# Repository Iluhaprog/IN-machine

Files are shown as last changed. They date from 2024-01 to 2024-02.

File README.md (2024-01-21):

> [!NOTE]
> Данный проект является учебным и предназначен в первую очередь для того
> чтобы разобраться и понять как работает вычислительное устройство на самом 
> низком уровне.

В данный момент проект на стадии разработки печатных плат и сборки физического 
устройства. 

Сейчас уже созданы и заказанны платы для АЛУ и Регистра флагов.

В процессе создания блок пользовательских регистров и счетчики команд и микро команд.

Сейчас в планы входят:
- [ ] - доработать схему управляющего устройства для работы с LCD 12864 экраном по SPI
- [ ] - разработка платы расширения для того, чтобы данное вычислительно устройство могло работать с датчиками.
- [ ] - изучение возможностей данного устройства и его параметров

Более подробно о базовых возможностях данного вычислительного устройства можно узнать в директории docs/

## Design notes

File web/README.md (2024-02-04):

Это веб версия ЭВМ. 
Здесь можно запустить свою программу написанную на jmasm.

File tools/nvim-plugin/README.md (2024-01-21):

Этот файл добавляет подсветку синтаксиса для jmasm файлов.

Для его использования этот файл необходимо добавить в **{path}/{to}/{nvim}/plugins**

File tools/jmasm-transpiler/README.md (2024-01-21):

Данный инструмент позволяет транспилировать asm код в код исполняемый моделью
в логисиме или для запуска непосредственно на физическом устройстве.

Установка
```
npm install -g .
```

Примеры можно посмотреть в директории **examples/**

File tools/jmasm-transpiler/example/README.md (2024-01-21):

В примере содеджаться 4 файла и дирректории rom-build и logisim-build

Создание фалов для запуска в моделе, которая находится в logism'e используется
следущая команда:
```sh
jmasm --source '.\jumps-example.jmasm' --output './logisim-build/jumps-example'
```

Для создания bin файла, который можно использовать для прошивки ROM
```sh
jmasm --source '.\jumps-example.jmasm' --output './rom-build/jumps-example.bin' --format BIN_FILE
```

> Содержимое созданных файлов соответствует общей спецификации.

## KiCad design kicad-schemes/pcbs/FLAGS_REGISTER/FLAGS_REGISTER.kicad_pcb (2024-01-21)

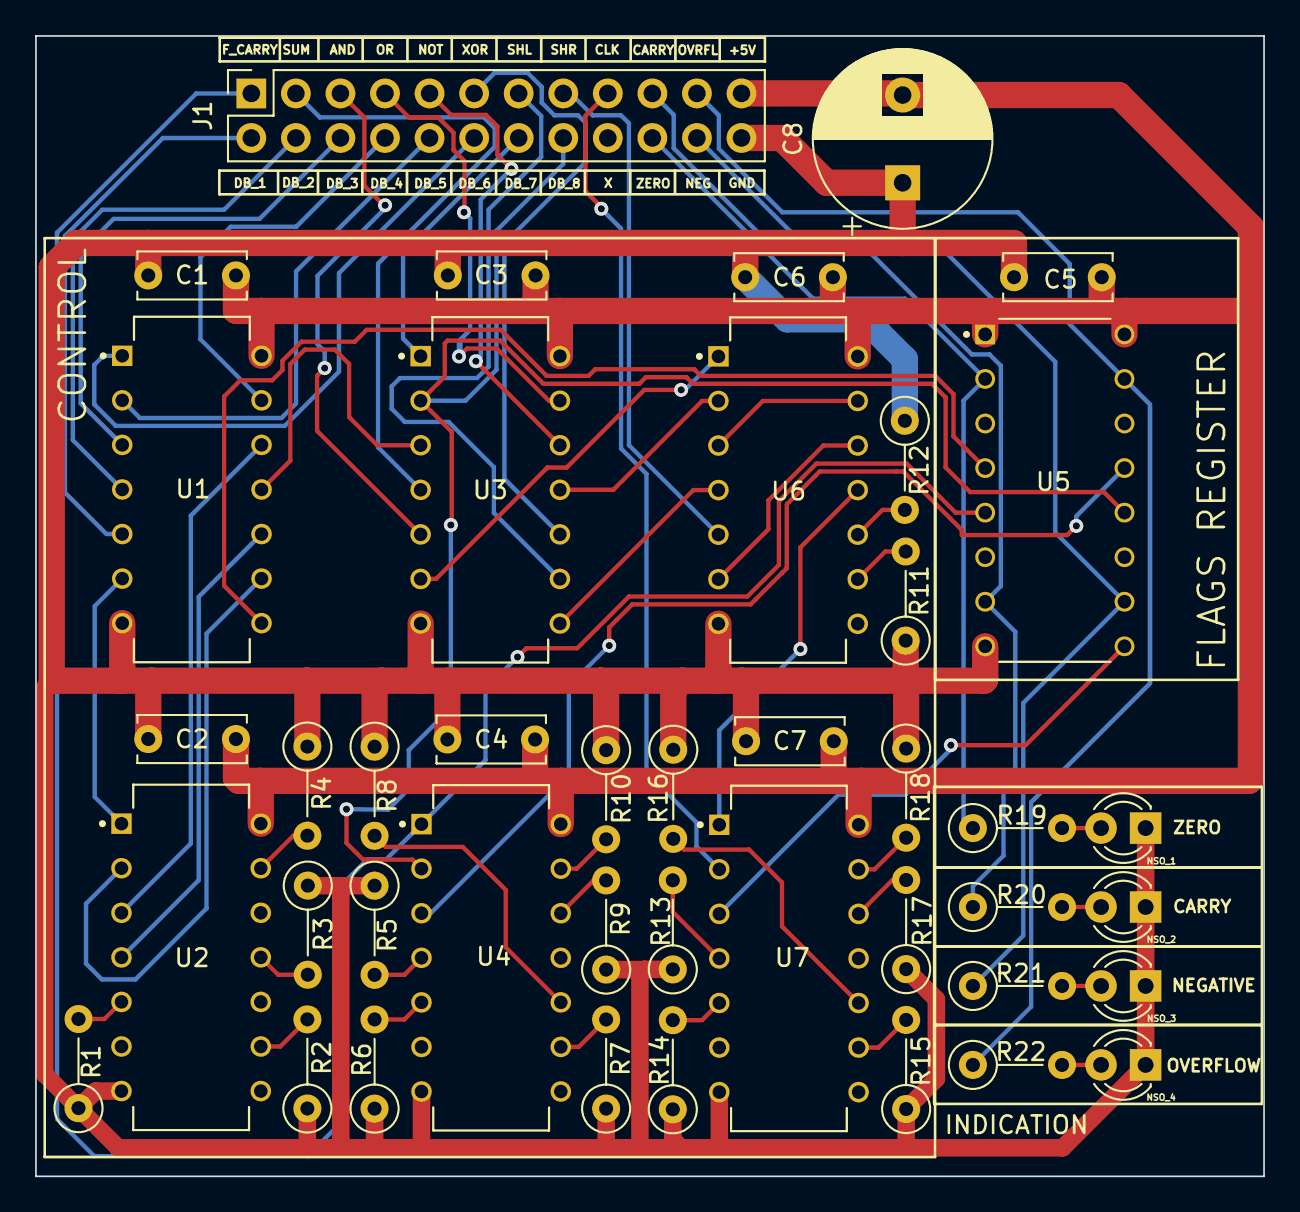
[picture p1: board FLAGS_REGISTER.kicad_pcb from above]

Board: 2 copper layers, 70.0 x 65.0 mm, 42 parts (0 on the bottom side), 59 nets.

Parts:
C1, C2, C3, C4, C5, C6, C7: C; C_Disc_D6.0mm_W2.5mm_P5.00mm
C8: C; CP_Radial_D10.0mm_P5.00mm
J1: Conn_02x12_Odd_Even; PinSocket_2x12_P2.54mm_Vertical
NSO_1, NSO_2, NSO_3, NSO_4: LED; LED_D3.0mm
R1, R2, R3, R4, R5, R6, R7, R8, R9, R10, R11, R12, R13, R14, R15, R16, R17, R18, R19, R20, R21, R22: R; R_Axial_DIN0207_L6.3mm_D2.5mm_P5.08mm_Vertical
U1: SN74HC27N; DIP794W45P254L1969H508Q14
U2: SN74HC14N; DIP794W45P254L1969H508Q14
U3, U6: SN74HC32N; DIP794W45P254L1969H508Q14
U4: SN74HC86N; DIP794W45P254L1969H508Q14
U5: SN74HC175N; DIP794W45P254L1969H508Q16
U7: SN74HC08N; DIP794W45P254L1969H508Q14

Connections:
+5V: C1.2, C2.2, C3.2, C4.2, C5.2, C6.2, C7.2, C8.2, J1.23, U1.14 (VCC), U2.14 (VCC), U3.14 (VCC), U4.14 (VCC), U5.1 (~CLR), U5.16 (VCC), U6.14 (VCC), U7.14 (VCC)
/CARRY: J1.19, R20.1, U5.7 (2Q)
/CLK: J1.17, U7.2 (1B)
/DB_1: J1.2, U1.5 (2C)
/DB_2: J1.4, U1.4 (2B)
/DB_3: J1.6, U1.3 (2A)
/DB_4: J1.8, U1.13 (1C)
/DB_5: J1.10, U1.2 (1B)
/DB_6: J1.12, U1.1 (1A)
/DB_7: J1.14, U3.1 (1A)
/DB_8: J1.16, U3.2 (1B), U4.2 (1B), U5.12 (3D)
/F_CARRY: J1.1, U4.1 (1A), U5.5 (2D)
/NEGATIVE: J1.22, R21.1, U5.10 (3Q)
/OVERFLOW: J1.21, R22.1, U5.15 (4Q)
/ZERO: J1.20, R19.1, U5.2 (1Q)
/n_AND_EN: J1.5, U3.5 (2B)
/n_NOT_EN: J1.9, U3.12 (4A)
/n_OR_EN: J1.7, U3.13 (4B)
/n_SHL_EN: J1.13, U3.9 (3A)
/n_SHR_EN: J1.15, U6.5 (2B)
/n_SUM_EN: J1.3, U3.4 (2A)
/n_XOR_EN: J1.11, U3.10 (3B)
CLK_FLAGS: U5.9 (CLK), U7.3 (1Y)
EN_WRITE_FLAGS: U6.11 (4Y), U7.1 (1A)
F_OVERFLOW: U4.3 (1Y), U5.13 (4D)
F_ZERO: U1.8 (3Y), U5.4 (1D)
GND: C1.1, C2.1, C3.1, C4.1, C5.1, C6.1, C7.1, C8.1, J1.24, NSO_1.1 (K), NSO_2.1 (K), NSO_3.1 (K), NSO_4.1 (K), R1.1, R2.1, R3.1, R4.1, R5.1, R6.1, R7.1, R8.1, R9.1, R10.1, R11.1, R12.1, R13.1, R14.1, R15.1, R16.1, R17.1, R18.1, U1.7 (GND), U2.7 (GND), U3.7 (GND), U4.7 (GND), U5.8 (GND), U6.7 (GND), U7.7 (GND)
NOT_OR_OR: U3.11 (4Y), U6.2 (1B)
unnamed: NSO_1.2 (A), R19.2
unnamed: NSO_2.2 (A), R20.2
unnamed: NSO_3.2 (A), R21.2
unnamed: NSO_4.2 (A), R22.2
unnamed: R1.2, U2.5 (3A)
unnamed: R2.2, U2.9 (4A)
unnamed: R3.2, U2.11 (5A)
unnamed: R4.2, U2.13 (6A)
unnamed: R5.2, U4.4 (2A)
unnamed: R6.2, U4.5 (2B)
unnamed: R7.2, U4.9 (3A)
unnamed: R8.2, U4.10 (3B)
unnamed: R9.2, U4.12 (4A)
unnamed: R10.2, U4.13 (4B)
unnamed: R11.2, U6.9 (3A)
unnamed: R12.2, U6.10 (3B)
unnamed: R13.2, U7.4 (2A)
unnamed: R14.2, U7.5 (2B)
unnamed: R15.2, U7.9 (3A)
unnamed: R16.2, U7.10 (3B)
unnamed: R17.2, U7.12 (4A)
unnamed: R18.2, U7.13 (4B)
O1_O2_O3: U1.6 (2Y), U2.1 (1A)
O4_O5_O6: U1.12 (1Y), U2.3 (2A)
SUM_OR_AND: U3.6 (2Y), U6.1 (1A)
SUM_OR_AND_OR_NOT_OR_OR: U6.3 (1Y), U6.13 (4B)
XOR_OR_SHL: U3.8 (3Y), U6.4 (2A)
XOR_OR_SHL_OR_SHR: U6.6 (2Y), U6.12 (4A)
n_O1_O2_O3: U1.9 (3A), U2.2 (1Y)
n_O4_O5_O6: U1.10 (3B), U2.4 (2Y)
n_O7_O8: U1.11 (3C), U3.3 (1Y)

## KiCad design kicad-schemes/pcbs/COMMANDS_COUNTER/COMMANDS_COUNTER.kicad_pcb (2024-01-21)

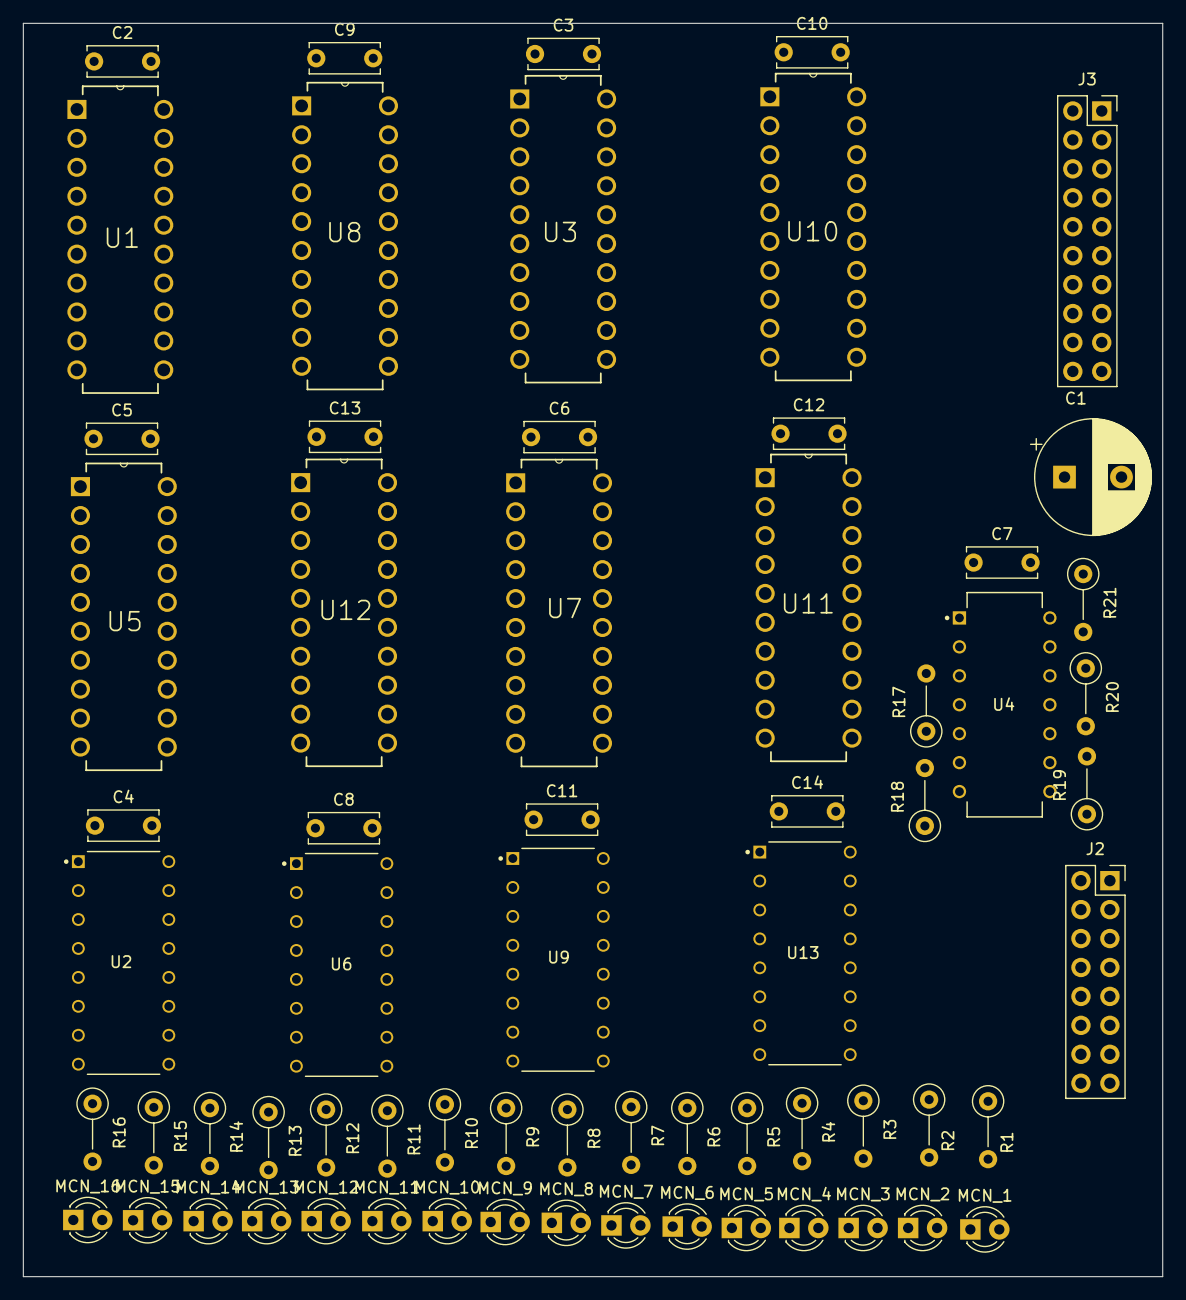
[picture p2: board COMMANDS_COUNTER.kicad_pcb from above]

Board: 2 copper layers, 100.0 x 110.0 mm, 66 parts (0 on the bottom side), 109 nets, no tracks yet.

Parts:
C1: C; CP_Radial_D10.0mm_P5.00mm
C2, C3, C4, C5, C6, C7, C8, C9, C10, C11, C12, C13, C14: C; C_Disc_D6.0mm_W2.5mm_P5.00mm
J2: Conn_02x08_Odd_Even; PinSocket_2x08_P2.54mm_Vertical
J3: Conn_02x10_Odd_Even; PinSocket_2x10_P2.54mm_Vertical
MCN_1, MCN_2, MCN_3, MCN_4, MCN_5, MCN_6, MCN_7, MCN_8, MCN_9, MCN_10, MCN_11, MCN_12, MCN_13, MCN_14, MCN_15, MCN_16: LED; LED_D3.0mm
R1, R2, R3, R4, R5, R6, R7, R8, R9, R10, R11, R12, R13, R14, R15, R16, R17, R18, R19, R20, R21: R; R_Axial_DIN0207_L6.3mm_D2.5mm_P5.08mm_Vertical
U1, U3, U8, U10: SN74HC377N; DIP254P762X508-20
U2, U6, U9, U13: SN74HC163N; DIP794W45P254L1969H508Q16
U4: SN74HC14N; DIP794W45P254L1969H508Q14
U5, U7, U11, U12: SN74HC244N; DIP254P762X508-20

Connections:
/AB1: J2.1, R1.1, U2.14 (QA), U3.3 (1D)
/AB2: J2.3, R2.1, U2.13 (QB), U3.4 (2D)
/AB3: J2.5, R3.1, U2.12 (QC), U3.7 (3D)
/AB4: J2.7, R4.1, U2.11 (QD), U3.8 (4D)
/AB5: J2.9, R5.1, U3.13 (5D), U6.14 (QA)
/AB6: J2.11, R6.1, U3.14 (6D), U6.13 (QB)
/AB7: J2.13, R7.1, U3.17 (7D), U6.12 (QC)
/AB8: J2.15, R8.1, U3.18 (8D), U6.11 (QD)
/AB9: J2.2, R9.1, U9.14 (QA), U10.3 (1D)
/AB10: J2.4, R10.1, U9.13 (QB), U10.4 (2D)
/AB11: J2.6, R11.1, U9.12 (QC), U10.7 (3D)
/AB12: J2.8, R12.1, U9.11 (QD), U10.8 (4D)
/AB13: J2.10, R13.1, U10.13 (5D), U13.14 (QA)
/AB14: J2.12, R14.1, U10.14 (6D), U13.13 (QB)
/AB15: J2.14, R15.1, U10.17 (7D), U13.12 (QC)
/AB16: J2.16, R16.1, U10.18 (8D), U13.11 (QD)
/CAR_n_EN1: J3.18, U3.1 (~CLKEN)
/CAR_n_EN2: J3.20, U10.1 (~CLKEN)
/CAR_n_EN_Out: J3.16, U7.1 (1~OE), U7.19 (2~OE), U11.1 (1~OE), U11.19 (2~OE)
/C_n_Clear: J3.4, U2.1 (~CLR), U6.1 (~CLR), U9.1 (~CLR), U13.1 (~CLR)
/C_n_Enable_Counter: J3.2, U2.7 (ENP), U6.7 (ENP), U9.7 (ENP), U13.7 (ENP)
/C_n_Enable_Load: J3.6, U2.9 (~LOAD), U6.9 (~LOAD), U9.9 (~LOAD), U13.9 (~LOAD)
/DB1: J3.5, U1.13 (5D), U8.13 (5D)
/DB2: J3.7, U1.8 (4D), U8.8 (4D)
/DB3: J3.9, U1.14 (6D), U8.14 (6D)
/DB4: J3.11, U1.7 (3D), U8.7 (3D)
/DB5: J3.13, U1.17 (7D), U8.17 (7D)
/DB6: J3.15, U1.4 (2D), U8.4 (2D)
/DB7: J3.17, U1.18 (8D), U8.18 (8D)
/DB8: J3.19, U1.3 (1D), U8.3 (1D)
/GND: C1.1, C2.1, C3.1, C4.1, C5.1, C6.1, C7.1, C8.1, C9.1, C10.1, C11.1, C12.1, C13.1, C14.1, J3.1, MCN_1.1 (K), MCN_2.1 (K), MCN_3.1 (K), MCN_4.1 (K), MCN_5.1 (K), MCN_6.1 (K), MCN_7.1 (K), MCN_8.1 (K), MCN_9.1 (K), MCN_10.1 (K), MCN_11.1 (K), MCN_12.1 (K), MCN_13.1 (K), MCN_14.1 (K), MCN_15.1 (K), MCN_16.1 (K), R17.1, R18.1, R19.1, R20.1, R21.1, U1.10 (GND), U2.8 (GND), U3.10 (GND), U4.7 (GND), U5.10 (GND), U6.8 (GND), U7.10 (GND), U8.10 (GND), U9.8 (GND), U10.10 (GND), U11.10 (GND), U12.10 (GND), U13.8 (GND)
/POWER: C1.2, C2.2, C3.2, C4.2, C5.2, C6.2, C7.2, C8.2, C9.2, C10.2, C11.2, C12.2, C13.2, C14.2, J3.3, U1.20 (VCC), U2.10 (ENT), U2.16 (VCC), U3.20 (VCC), U4.14 (VCC), U5.20 (VCC), U6.16 (VCC), U7.20 (VCC), U8.20 (VCC), U9.16 (VCC), U10.20 (VCC), U11.20 (VCC), U12.20 (VCC), U13.16 (VCC)
/UAR_n_EN1: J3.8, U1.1 (~CLKEN)
/UAR_n_EN2: J3.10, U8.1 (~CLKEN)
/UAR_n_EN_Out: J3.12, U5.1 (1~OE), U5.19 (2~OE), U12.1 (1~OE), U12.19 (2~OE)
CLK: J3.14, U1.11 (CLK), U2.2 (CLK), U4.1 (1A), U6.2 (CLK), U8.11 (CLK), U9.2 (CLK), U13.2 (CLK)
CR_O_1: U2.3 (A), U5.3 (2Y4), U7.18 (1Y1)
CR_O_2: U2.4 (B), U5.18 (1Y1), U7.16 (1Y2)
CR_O_3: U2.5 (C), U5.5 (2Y3), U7.14 (1Y3)
CR_O_4: U2.6 (D), U5.16 (1Y2), U7.12 (1Y4)
CR_O_5: U5.7 (2Y2), U6.3 (A), U7.9 (2Y1)
CR_O_6: U5.14 (1Y3), U6.4 (B), U7.7 (2Y2)
CR_O_7: U5.9 (2Y1), U6.5 (C), U7.5 (2Y3)
CR_O_8: U5.12 (1Y4), U6.6 (D), U7.3 (2Y4)
CR_O_9: U9.3 (A), U11.18 (1Y1), U12.3 (2Y4)
CR_O_10: U9.4 (B), U11.16 (1Y2), U12.18 (1Y1)
CR_O_11: U9.5 (C), U11.14 (1Y3), U12.5 (2Y3)
CR_O_12: U9.6 (D), U11.12 (1Y4), U12.16 (1Y2)
CR_O_13: U11.9 (2Y1), U12.7 (2Y2), U13.3 (A)
CR_O_14: U11.7 (2Y2), U12.14 (1Y3), U13.4 (B)
CR_O_15: U11.5 (2Y3), U12.9 (2Y1), U13.5 (C)
CR_O_16: U11.3 (2Y4), U12.12 (1Y4), U13.6 (D)
C_RCO_1: U2.15 (RCO), U6.10 (ENT)
C_RCO_2: U6.15 (RCO), U9.10 (ENT)
C_RCO_3: U9.15 (RCO), U13.10 (ENT)
unnamed: MCN_1.2 (A), R1.2
unnamed: MCN_2.2 (A), R2.2
unnamed: MCN_3.2 (A), R3.2
unnamed: MCN_4.2 (A), R4.2
unnamed: MCN_5.2 (A), R5.2
unnamed: MCN_6.2 (A), R6.2
unnamed: MCN_7.2 (A), R7.2
unnamed: MCN_8.2 (A), R8.2
unnamed: MCN_9.2 (A), R9.2
unnamed: MCN_10.2 (A), R10.2
unnamed: MCN_11.2 (A), R11.2
unnamed: MCN_12.2 (A), R12.2
unnamed: MCN_13.2 (A), R13.2
unnamed: MCN_14.2 (A), R14.2
unnamed: MCN_15.2 (A), R15.2
unnamed: MCN_16.2 (A), R16.2
unnamed: R17.2, U4.3 (2A)
unnamed: R18.2, U4.5 (3A)
unnamed: R19.2, U4.9 (4A)
unnamed: R20.2, U4.11 (5A)
unnamed: R21.2, U4.13 (6A)
in_UAR_O_1: U1.12 (5Q), U5.17 (2A4)
in_UAR_O_2: U1.9 (4Q), U5.2 (1A1)
in_UAR_O_3: U1.15 (6Q), U5.15 (2A3)
in_UAR_O_4: U1.6 (3Q), U5.4 (1A2)
in_UAR_O_5: U1.16 (7Q), U5.13 (2A2)
in_UAR_O_6: U1.5 (2Q), U5.6 (1A3)
in_UAR_O_7: U1.19 (8Q), U5.11 (2A1)
in_UAR_O_8: U1.2 (1Q), U5.8 (1A4)
in_UAR_O_9: U8.12 (5Q), U12.17 (2A4)
in_UAR_O_10: U8.9 (4Q), U12.2 (1A1)
in_UAR_O_11: U8.15 (6Q), U12.15 (2A3)
in_UAR_O_12: U8.6 (3Q), U12.4 (1A2)
in_UAR_O_13: U8.16 (7Q), U12.13 (2A2)
in_UAR_O_14: U8.5 (2Q), U12.6 (1A3)
in_UAR_O_15: U8.19 (8Q), U12.11 (2A1)
in_UAR_O_16: U8.2 (1Q), U12.8 (1A4)
in_СAR_O_1: U3.2 (1Q), U7.2 (1A1)
in_СAR_O_2: U3.5 (2Q), U7.4 (1A2)
in_СAR_O_3: U3.6 (3Q), U7.6 (1A3)
in_СAR_O_4: U3.9 (4Q), U7.8 (1A4)
in_СAR_O_5: U3.12 (5Q), U7.11 (2A1)
in_СAR_O_6: U3.15 (6Q), U7.13 (2A2)
in_СAR_O_7: U3.16 (7Q), U7.15 (2A3)
in_СAR_O_8: U3.19 (8Q), U7.17 (2A4)
in_СAR_O_9: U10.2 (1Q), U11.2 (1A1)
in_СAR_O_10: U10.5 (2Q), U11.4 (1A2)
in_СAR_O_11: U10.6 (3Q), U11.6 (1A3)
in_СAR_O_12: U10.9 (4Q), U11.8 (1A4)
in_СAR_O_13: U10.12 (5Q), U11.11 (2A1)
in_СAR_O_14: U10.15 (6Q), U11.13 (2A2)
in_СAR_O_15: U10.16 (7Q), U11.15 (2A3)
in_СAR_O_16: U10.19 (8Q), U11.17 (2A4)
n_CLK: U3.11 (CLK), U4.2 (1Y), U10.11 (CLK)

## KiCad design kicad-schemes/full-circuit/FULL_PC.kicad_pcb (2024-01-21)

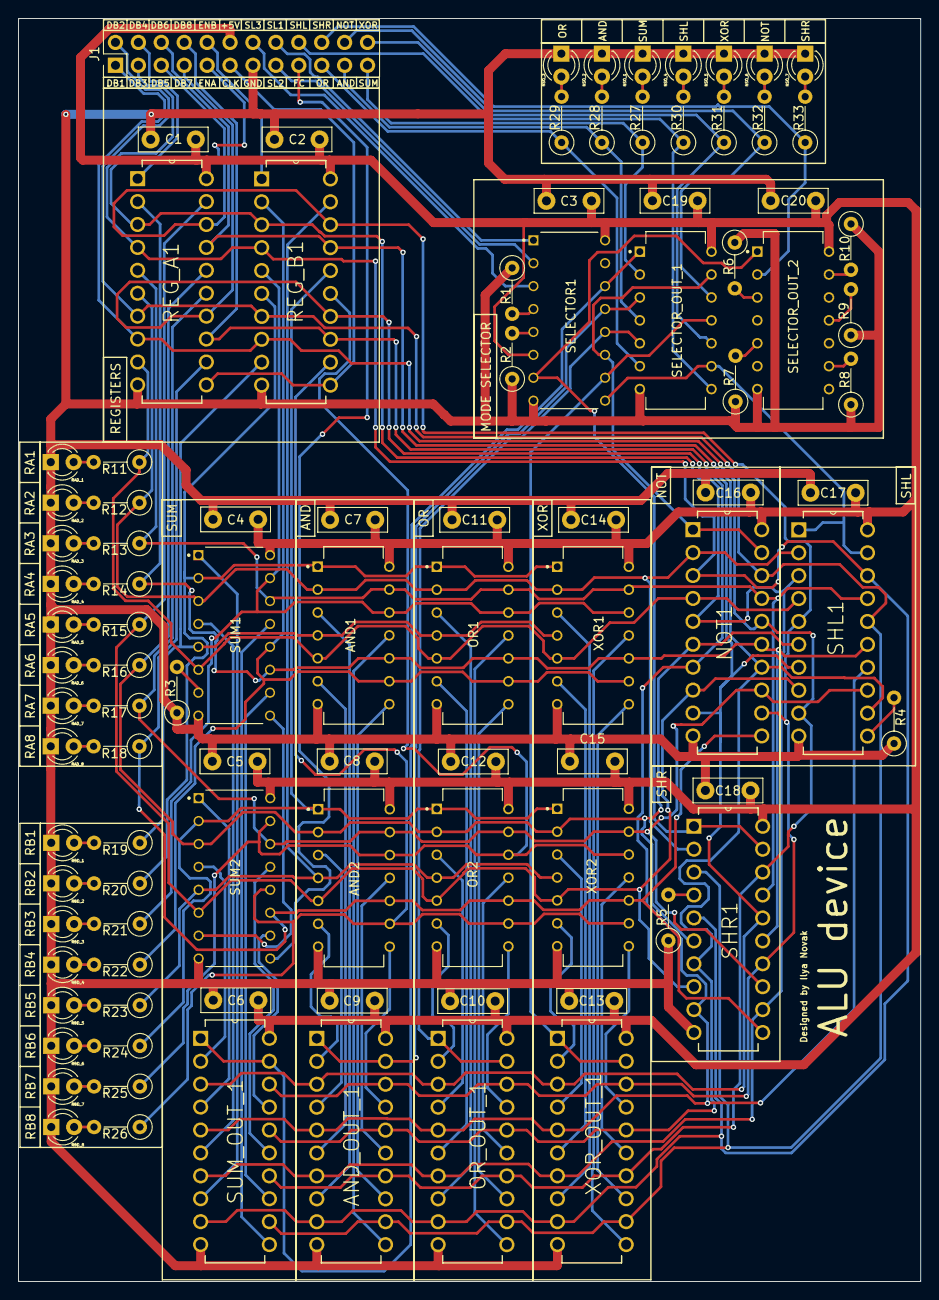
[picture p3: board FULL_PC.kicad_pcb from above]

Board: 2 copper layers, 100.0 x 140.0 mm, 97 parts (0 on the bottom side), 113 nets.

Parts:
AND1, AND2: SN74HC08N; DIP794W45P254L1969H508Q14
AND_OUT_1: SN74HC244N; DIP254P762X508-20
C1, C2, C3, C4, C5, C6, C7, C8, C9, C10, C11, C12, C13, C14, C15, C16, C17, C18, C19, C20: C; C_Disc_D7.5mm_W2.5mm_P5.00mm
J1: Conn_02x12_Counter_Clockwise; PinHeader_2x12_P2.54mm_Vertical
NOT1: SN74HC240N; DIP254P762X508-20
NSO_1, NSO_2, NSO_3, NSO_4, NSO_5, NSO_6, NSO_7: LED; LED_D3.0mm
OR1, OR2: SN74HC32N; DIP794W45P254L1969H508Q14
OR_OUT_1: SN74HC244N; DIP254P762X508-20
R1, R2, R3, R4, R5, R6, R7, R8, R9, R10, R11, R12, R13, R14, R15, R16, R17, R18, R19, R20, R21, R22, R23, R24, R25, R26, R27, R28, R29, R30, R31, R32, R33: R; R_Axial_DIN0207_L6.3mm_D2.5mm_P5.08mm_Vertical
RAD_1, RAD_2, RAD_3, RAD_4, RAD_5, RAD_6, RAD_7, RAD_8: LED; LED_D3.0mm
RBD_1, RBD_2, RBD_3, RBD_4, RBD_5, RBD_6, RBD_7, RBD_8: LED; LED_D3.0mm
REG_A1: SN74HC377N; DIP254P762X508-20
REG_B1: SN74HC377N; DIP254P762X508-20
SELECTOR1: SN74HC138N; DIP794W45P254L1969H508Q16
SELECTOR_OUT_1, SELECTOR_OUT_2: SN74HC14N; DIP794W45P254L1969H508Q14
SHL1: SN74HC244N; DIP254P762X508-20
SHR1: SN74HC244N; DIP254P762X508-20
SUM1, SUM2: SN74HC283N; DIP794W45P254L1969H508Q16
SUM_OUT_1: SN74HC244N; DIP254P762X508-20
XOR1, XOR2: SN74HC86N; DIP794W45P254L1969H508Q14
XOR_OUT_1: SN74HC244N; DIP254P762X508-20

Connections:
+5V: AND1.14 (VCC), AND2.14 (VCC), AND_OUT_1.20 (VCC), C1.2, C2.2, C3.2, C4.2, C5.2, C6.2, C7.2, C8.2, C9.2, C10.2, C11.2, C12.2, C13.2, C14.2, C15.2, C16.2, C17.2, C18.2, C19.2, C20.2, J1.12, NOT1.20 (VCC), OR1.14 (VCC), OR2.14 (VCC), OR_OUT_1.20 (VCC), REG_A1.20 (VCC), REG_B1.20 (VCC), SELECTOR1.6 (G1), SELECTOR1.16 (VCC), SELECTOR_OUT_1.14 (VCC), SELECTOR_OUT_2.14 (VCC), SHL1.20 (VCC), SHR1.20 (VCC), SUM1.16 (Vcc), SUM2.16 (Vcc), SUM_OUT_1.20 (VCC), XOR1.14 (VCC), XOR2.14 (VCC), XOR_OUT_1.20 (VCC)
/ALU/CLK: J1.11, REG_A1.11 (CLK), REG_B1.11 (CLK)
/ALU/DB_1: AND_OUT_1.14 (1Y3), J1.1, NOT1.16 (1Y2), OR_OUT_1.14 (1Y3), REG_A1.8 (4D), REG_B1.8 (4D), SHL1.9 (2Y1), SHR1.18 (1Y1), SUM_OUT_1.14 (1Y3), XOR_OUT_1.14 (1Y3)
/ALU/DB_2: AND_OUT_1.12 (1Y4), J1.2, NOT1.18 (1Y1), OR_OUT_1.12 (1Y4), REG_A1.7 (3D), REG_B1.7 (3D), SHL1.16 (1Y2), SHR1.3 (2Y4), SUM_OUT_1.12 (1Y4), XOR_OUT_1.12 (1Y4)
/ALU/DB_3: AND_OUT_1.9 (2Y1), J1.3, NOT1.3 (2Y4), OR_OUT_1.9 (2Y1), REG_A1.4 (2D), REG_B1.4 (2D), SHL1.18 (1Y1), SHR1.5 (2Y3), SUM_OUT_1.9 (2Y1), XOR_OUT_1.9 (2Y1)
/ALU/DB_4: AND_OUT_1.7 (2Y2), J1.4, NOT1.5 (2Y3), OR_OUT_1.7 (2Y2), REG_A1.3 (1D), REG_B1.3 (1D), SHL1.3 (2Y4), SHR1.12 (1Y4), SUM_OUT_1.7 (2Y2), XOR_OUT_1.7 (2Y2)
/ALU/DB_5: AND_OUT_1.18 (1Y1), J1.5, NOT1.12 (1Y4), OR_OUT_1.18 (1Y1), REG_A1.18 (8D), REG_B1.18 (8D), SHL1.5 (2Y3), SHR1.14 (1Y3), SUM_OUT_1.18 (1Y1), XOR_OUT_1.18 (1Y1)
/ALU/DB_6: AND_OUT_1.16 (1Y2), J1.6, NOT1.14 (1Y3), OR_OUT_1.16 (1Y2), REG_A1.17 (7D), REG_B1.17 (7D), SHL1.12 (1Y4), SHR1.7 (2Y2), SUM_OUT_1.16 (1Y2), XOR_OUT_1.16 (1Y2)
/ALU/DB_7: AND_OUT_1.5 (2Y3), J1.7, NOT1.7 (2Y2), OR_OUT_1.5 (2Y3), REG_A1.14 (6D), REG_B1.14 (6D), SHL1.14 (1Y3), SHR1.9 (2Y1), SUM_OUT_1.5 (2Y3), XOR_OUT_1.5 (2Y3)
/ALU/DB_8: AND_OUT_1.3 (2Y4), J1.8, NOT1.9 (2Y1), OR_OUT_1.3 (2Y4), REG_A1.13 (5D), REG_B1.13 (5D), SHL1.7 (2Y2), SHR1.16 (1Y2), SUM_OUT_1.3 (2Y4), XOR_OUT_1.3 (2Y4)
/ALU/EN_A: J1.9, REG_A1.1 (~CLKEN)
/ALU/EN_B: J1.10, REG_B1.1 (~CLKEN)
/ALU/F_CARRY: J1.17, SUM2.9 (C4)
/ALU/SL_1: J1.16, SELECTOR1.1 (A)
/ALU/SL_2: J1.15, SELECTOR1.2 (B)
/ALU/SL_3: J1.14, SELECTOR1.3 (C)
/ALU/n_AND_EN: J1.21, R28.1, SELECTOR_OUT_1.4 (2Y)
/ALU/n_NOT_EN: J1.22, R32.1, SELECTOR_OUT_1.12 (6Y)
/ALU/n_OR_EN: J1.19, R29.1, SELECTOR_OUT_1.6 (3Y)
/ALU/n_SHL_EN: J1.18, R30.1, SELECTOR_OUT_1.8 (4Y)
/ALU/n_SHR_EN: J1.20, R33.1, SELECTOR_OUT_2.2 (1Y)
/ALU/n_SUM_EN: J1.23, R27.1, SELECTOR_OUT_1.2 (1Y)
/ALU/n_XOR_EN: J1.24, R31.1, SELECTOR_OUT_1.10 (5Y)
AND_EN: AND_OUT_1.1 (1~OE), AND_OUT_1.19 (2~OE), SELECTOR1.13 (Y2), SELECTOR_OUT_1.3 (2A)
AND_O_1: AND1.6 (2Y), AND_OUT_1.6 (1A3)
AND_O_2: AND1.3 (1Y), AND_OUT_1.8 (1A4)
AND_O_3: AND1.11 (4Y), AND_OUT_1.11 (2A1)
AND_O_4: AND1.8 (3Y), AND_OUT_1.13 (2A2)
AND_O_5: AND2.6 (2Y), AND_OUT_1.2 (1A1)
AND_O_6: AND2.3 (1Y), AND_OUT_1.4 (1A2)
AND_O_7: AND2.11 (4Y), AND_OUT_1.15 (2A3)
AND_O_8: AND2.8 (3Y), AND_OUT_1.17 (2A4)
GND: AND1.7 (GND), AND2.7 (GND), AND_OUT_1.10 (GND), C1.1, C2.1, C3.1, C4.1, C5.1, C6.1, C7.1, C8.1, C9.1, C10.1, C11.1, C12.1, C13.1, C14.1, C15.1, C16.1, C17.1, C18.1, C19.1, C20.1, J1.13, NOT1.10 (GND), NSO_1.1 (K), NSO_2.1 (K), NSO_3.1 (K), NSO_4.1 (K), NSO_5.1 (K), NSO_6.1 (K), NSO_7.1 (K), OR1.7 (GND), OR2.7 (GND), OR_OUT_1.10 (GND), R1.1, R2.1, R3.1, R4.1, R5.1, R6.1, R7.1, R8.1, R9.1, R10.1, RAD_1.1 (K), RAD_2.1 (K), RAD_3.1 (K), RAD_4.1 (K), RAD_5.1 (K), RAD_6.1 (K), RAD_7.1 (K), RAD_8.1 (K), RBD_1.1 (K), RBD_2.1 (K), RBD_3.1 (K), RBD_4.1 (K), RBD_5.1 (K), RBD_6.1 (K), RBD_7.1 (K), RBD_8.1 (K), REG_A1.10 (GND), REG_B1.10 (GND), SELECTOR1.8 (GND), SELECTOR_OUT_1.7 (GND), SELECTOR_OUT_2.7 (GND), SHL1.10 (GND), SHR1.10 (GND), SUM1.8 (GND), SUM2.8 (GND), SUM_OUT_1.10 (GND), XOR1.7 (GND), XOR2.7 (GND), XOR_OUT_1.10 (GND)
NOT_EN: NOT1.1 (1~OE), NOT1.19 (2~OE), SELECTOR1.11 (Y4), SELECTOR_OUT_1.13 (6A)
unnamed: NSO_1.2 (A), R27.2
unnamed: NSO_2.2 (A), R28.2
unnamed: NSO_3.2 (A), R29.2
unnamed: NSO_4.2 (A), R30.2
unnamed: NSO_5.2 (A), R31.2
unnamed: NSO_6.2 (A), R32.2
unnamed: NSO_7.2 (A), R33.2
unnamed: R11.2, RAD_1.2 (A)
unnamed: R12.2, RAD_2.2 (A)
unnamed: R13.2, RAD_3.2 (A)
unnamed: R14.2, RAD_4.2 (A)
unnamed: R15.2, RAD_5.2 (A)
unnamed: R16.2, RAD_6.2 (A)
unnamed: R17.2, RAD_7.2 (A)
unnamed: R18.2, RAD_8.2 (A)
unnamed: R19.2, RBD_1.2 (A)
unnamed: R20.2, RBD_2.2 (A)
unnamed: R21.2, RBD_3.2 (A)
unnamed: R22.2, RBD_4.2 (A)
unnamed: R23.2, RBD_5.2 (A)
unnamed: R24.2, RBD_6.2 (A)
unnamed: R25.2, RBD_7.2 (A)
unnamed: R26.2, RBD_8.2 (A)
unnamed: R1.2, SELECTOR1.4 (~G2A)
unnamed: R2.2, SELECTOR1.5 (~G2B)
unnamed: R6.2, SELECTOR_OUT_2.3 (2A)
unnamed: R7.2, SELECTOR_OUT_2.5 (3A)
unnamed: R8.2, SELECTOR_OUT_2.9 (4A)
unnamed: R9.2, SELECTOR_OUT_2.11 (5A)
unnamed: R10.2, SELECTOR_OUT_2.13 (6A)
unnamed: R4.2, SHL1.11 (2A1)
unnamed: R5.2, SHR1.4 (1A2)
unnamed: R3.2, SUM1.7 (C0)
unnamed: SUM1.9 (C4), SUM2.7 (C0)
OR_EN: OR_OUT_1.1 (1~OE), OR_OUT_1.19 (2~OE), SELECTOR1.12 (Y3), SELECTOR_OUT_1.5 (3A)
OR_O_1: OR1.6 (2Y), OR_OUT_1.6 (1A3)
OR_O_2: OR1.3 (1Y), OR_OUT_1.8 (1A4)
OR_O_3: OR1.11 (4Y), OR_OUT_1.11 (2A1)
OR_O_4: OR1.8 (3Y), OR_OUT_1.13 (2A2)
OR_O_5: OR2.6 (2Y), OR_OUT_1.2 (1A1)
OR_O_6: OR2.3 (1Y), OR_OUT_1.4 (1A2)
OR_O_7: OR2.11 (4Y), OR_OUT_1.15 (2A3)
OR_O_8: OR2.8 (3Y), OR_OUT_1.17 (2A4)
RA_1: AND1.5 (2B), NOT1.4 (1A2), OR1.5 (2B), R11.1, REG_A1.9 (4Q), SHL1.4 (1A2), SUM1.6 (B1), XOR1.5 (2B)
RA_2: AND1.2 (1B), NOT1.2 (1A1), OR1.2 (1B), R12.1, REG_A1.6 (3Q), SHL1.2 (1A1), SHR1.2 (1A1), SUM1.3 (A2), XOR1.2 (1B)
RA_3: AND1.13 (4B), NOT1.17 (2A4), OR1.13 (4B), R13.1, REG_A1.5 (2Q), SHL1.17 (2A4), SHR1.17 (2A4), SUM1.14 (A3), XOR1.13 (4B)
RA_4: AND1.10 (3B), NOT1.15 (2A3), OR1.10 (3B), R14.1, REG_A1.2 (1Q), SHL1.15 (2A3), SHR1.15 (2A3), SUM1.11 (B4), XOR1.10 (3B)
RA_5: AND2.5 (2B), NOT1.8 (1A4), OR2.5 (2B), R15.1, REG_A1.19 (8Q), SHL1.8 (1A4), SHR1.8 (1A4), SUM2.6 (B1), XOR2.5 (2B)
RA_6: AND2.2 (1B), NOT1.6 (1A3), OR2.2 (1B), R16.1, REG_A1.16 (7Q), SHL1.6 (1A3), SHR1.6 (1A3), SUM2.3 (A2), XOR2.2 (1B)
RA_7: AND2.13 (4B), NOT1.13 (2A2), OR2.13 (4B), R17.1, REG_A1.15 (6Q), SHL1.13 (2A2), SHR1.13 (2A2), SUM2.14 (A3), XOR2.13 (4B)
RA_8: AND2.10 (3B), NOT1.11 (2A1), OR2.10 (3B), R18.1, REG_A1.12 (5Q), SHR1.11 (2A1), SUM2.11 (B4), XOR2.10 (3B)
RB_1: AND1.4 (2A), OR1.4 (2A), R19.1, REG_B1.9 (4Q), SUM1.5 (A1), XOR1.4 (2A)
RB_2: AND1.1 (1A), OR1.1 (1A), R20.1, REG_B1.6 (3Q), SUM1.2 (B2), XOR1.1 (1A)
RB_3: AND1.12 (4A), OR1.12 (4A), R21.1, REG_B1.5 (2Q), SUM1.15 (B3), XOR1.12 (4A)
RB_4: AND1.9 (3A), OR1.9 (3A), R22.1, REG_B1.2 (1Q), SUM1.12 (A4), XOR1.9 (3A)
RB_5: AND2.4 (2A), OR2.4 (2A), R23.1, REG_B1.19 (8Q), SUM2.5 (A1), XOR2.4 (2A)
RB_6: AND2.1 (1A), OR2.1 (1A), R24.1, REG_B1.16 (7Q), SUM2.2 (B2), XOR2.1 (1A)
RB_7: AND2.12 (4A), OR2.12 (4A), R25.1, REG_B1.15 (6Q), SUM2.15 (B3), XOR2.12 (4A)
RB_8: AND2.9 (3A), OR2.9 (3A), R26.1, REG_B1.12 (5Q), SUM2.12 (A4), XOR2.9 (3A)
SHL_EN: SELECTOR1.9 (Y6), SELECTOR_OUT_1.9 (4A), SHL1.1 (1~OE), SHL1.19 (2~OE)
SHR_EN: SELECTOR1.7 (Y7), SELECTOR_OUT_2.1 (1A), SHR1.1 (1~OE), SHR1.19 (2~OE)
SUM_EN: SELECTOR1.14 (Y1), SELECTOR_OUT_1.1 (1A), SUM_OUT_1.1 (1~OE), SUM_OUT_1.19 (2~OE)
SUM_O_1: SUM1.4 (S1), SUM_OUT_1.6 (1A3)
SUM_O_2: SUM1.1 (S2), SUM_OUT_1.8 (1A4)
SUM_O_3: SUM1.13 (S3), SUM_OUT_1.11 (2A1)
SUM_O_4: SUM1.10 (S4), SUM_OUT_1.13 (2A2)
SUM_O_5: SUM2.4 (S1), SUM_OUT_1.2 (1A1)
SUM_O_6: SUM2.1 (S2), SUM_OUT_1.4 (1A2)
SUM_O_7: SUM2.13 (S3), SUM_OUT_1.15 (2A3)
SUM_O_8: SUM2.10 (S4), SUM_OUT_1.17 (2A4)
XOR_EN: SELECTOR1.10 (Y5), SELECTOR_OUT_1.11 (5A), XOR_OUT_1.1 (1~OE), XOR_OUT_1.19 (2~OE)
XOR_O_1: XOR1.6 (2Y), XOR_OUT_1.6 (1A3)
XOR_O_2: XOR1.3 (1Y), XOR_OUT_1.8 (1A4)
XOR_O_3: XOR1.11 (4Y), XOR_OUT_1.11 (2A1)
XOR_O_4: XOR1.8 (3Y), XOR_OUT_1.13 (2A2)
XOR_O_5: XOR2.6 (2Y), XOR_OUT_1.2 (1A1)
XOR_O_6: XOR2.3 (1Y), XOR_OUT_1.4 (1A2)
XOR_O_7: XOR2.11 (4Y), XOR_OUT_1.15 (2A3)
XOR_O_8: XOR2.8 (3Y), XOR_OUT_1.17 (2A4)

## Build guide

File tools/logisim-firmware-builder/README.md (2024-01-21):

Для использования данной утилиты необходимо:
1. Перейти в директорию tools/logisim-firmware-buildre
2. Прописать команду
```sh
npm install -g .
```
3. Запустить следующим образом
```sh
cfbu  --docs docs\rom-firmware --output ./build --source-circuit .\logisim-model\PC_with_ROM_CU.circ --open-in-logisim
```

> В случае отображения ошибок необходимо добавить дополнительные параметры 
> указывающие нахождение java и logisim-eveolution. 
> ```sh
> cfbu ...  --path-to-java '{path}' --path-to-logisim '{path}' 
> ```

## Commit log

2024-01-21 feat: Added full circuit of pc. Added pcb for alu, because it in full circuit
    [CELLS.kicad_sch, FULL_PC.kicad_pcb, FULL_PC.kicad_sch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]
2024-01-21 feat: Added PCB's for flags register and started commands counters PCB.
    [COMMANDS_COUNTER.kicad_pcb, COMMANDS_COUNTER.kicad_sch, FLAGS_REGISTER.kicad_pcb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]
2024-01-21 feat: Added main model modifications that allows create PCB's. This schemes for tests can use build files from tools\jmasm-transpiler\example.
2024-02-04 feat: Added tool that allow run circuits. Started development of web version of PC.
